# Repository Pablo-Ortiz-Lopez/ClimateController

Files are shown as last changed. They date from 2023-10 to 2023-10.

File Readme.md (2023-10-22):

# ClimateController

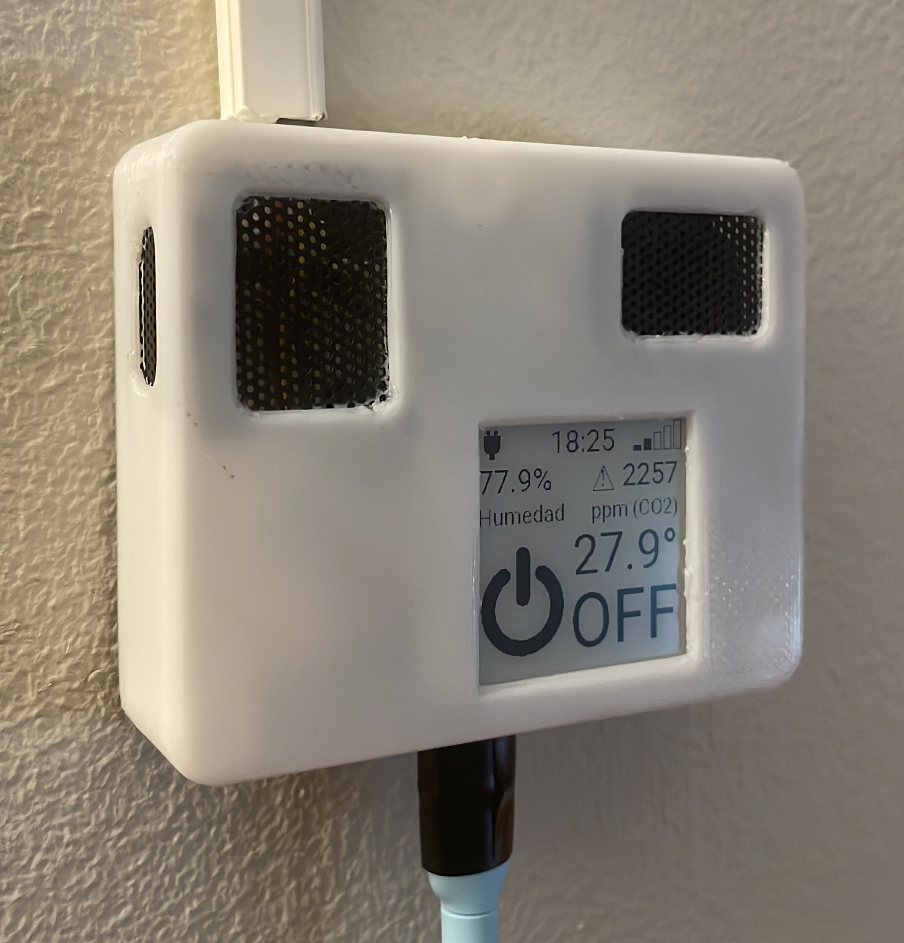
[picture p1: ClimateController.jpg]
My ClimateController


This is my attempt at creating a climate controller for my IOT platform. 

This repository contains everything you need to build and customize your very own ESP8266-based climate controller. 

Whether you want to monitor temperature, humidity, CO2 levels, control a thermostat, manage appliances with a relay, or even handle IR-based air conditioning units, the ClimateController has you covered. 

This README will guide you through the repository's contents and how to get started with your climate controller project. Keep in mind this project was tailor made to cover my needs, so it will most likely need some adaptations for your use case. Feel free to ask me anything you may need about the project.

## Contents

This repository is organized into three main folders, each serving a unique purpose for your climate controller project:

### 1. Electronics

The "electronics" folder contains all the hardware-related materials you'll need:

- **Schematic**: Find the schematic diagram that outlines the electrical connections and components used in the climate controller.

- **PCB Design**: Get the PCB (Printed Circuit Board) design files to manufacture your own climate controller board. You can customize it to suit your needs or use the provided design.

- **KiCad Project**: The KiCad project files are available for further customization and refinement of the PCB design.

### 2. External Case

In the "external_case" folder, you'll find everything related to the physical housing of your climate controller:

- **Fusion360 Project**: Access the Fusion360 project, which contains the 3D model of the external case. You can modify and personalize the design to your liking.

- **Pregenerated Case Designs**: I've included pregenerated presets in .3mf format for 3D printing the external case. Use these presets if you don't have access to Fusion360.

### 3. Firmware

The "firmware" directory contains:

- **Example YAML File**: Use the provided YAML file as a starting point for programming your climate controller with ESPHome. You can adapt and expand upon this file to tailor the device's behavior to your needs.

## Device Features

The ClimateController is highly customizable and can be configured to suit your unique requirements. Here are some of the device's capabilities:

- **Temperature and Humidity Readings**: Monitor environmental temperature and humidity levels.

- **CO2 Readings**: Measure and track carbon dioxide levels in your surroundings.

- **Thermostat Control**: Control a thermostat or other appliances using a relay. This feature enables you to manage heating or cooling systems and other devices with ease.

- **IR-Based Air Conditioner Control**: Remotely manage IR-based air conditioning units for optimal climate control.

- **Display Options**: Choose between an OLED or E-INK display, offering flexibility for your preferred user interface.

## Getting Started

To begin your ClimateController project, follow these steps:

1. Clone this repository to your local machine using Git:
   ```
   git clone git@github.com:Pablo-Ortiz-Lopez/ClimateController.git
   ```

2. Explore the relevant folders to access the hardware and firmware resources.

3. Customize the PCB design, 3D case model, and firmware according to your project requirements.

4. Manufacture the PCB and 3D print the external case.

5. Load and customize the provided yml file into ESPHome, and then load it into the device. If you don't already have an ESPHome environment, I recommend looking into my [HomePanel](https://github.com/Pablo-Ortiz-Lopez/HomePanel) project.

6. Assemble the components and enjoy your personalized climate controller.

## Contributing

If you have improvements, bug fixes, or new features to contribute to the ClimateController project, feel free to create a pull request. I will welcome your contributions and ideas to make this project even better.

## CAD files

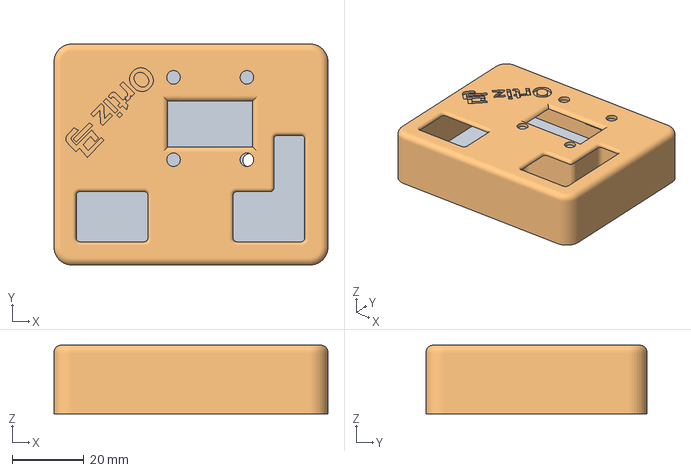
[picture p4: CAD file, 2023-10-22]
external_case/ClimateController External Case OLED display.3mf
76.5 x 61.8 x 19.2 mm
Back Cover
Front Cover

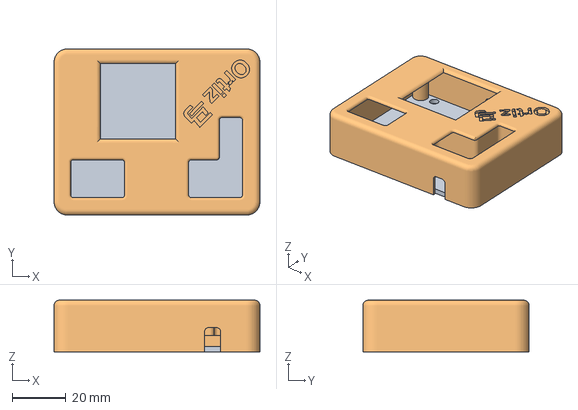
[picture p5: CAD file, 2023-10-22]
external_case/ClimateController External Case EINK display + IR.3mf
76.5 x 61.8 x 19.2 mm
Back Cover
Front Cover

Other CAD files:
external_case/ClimateController External Case EINK display.3mf
external_case/ClimateController External Case OLED display + IR.3mf
external_case/ClimateController External Case.f3d

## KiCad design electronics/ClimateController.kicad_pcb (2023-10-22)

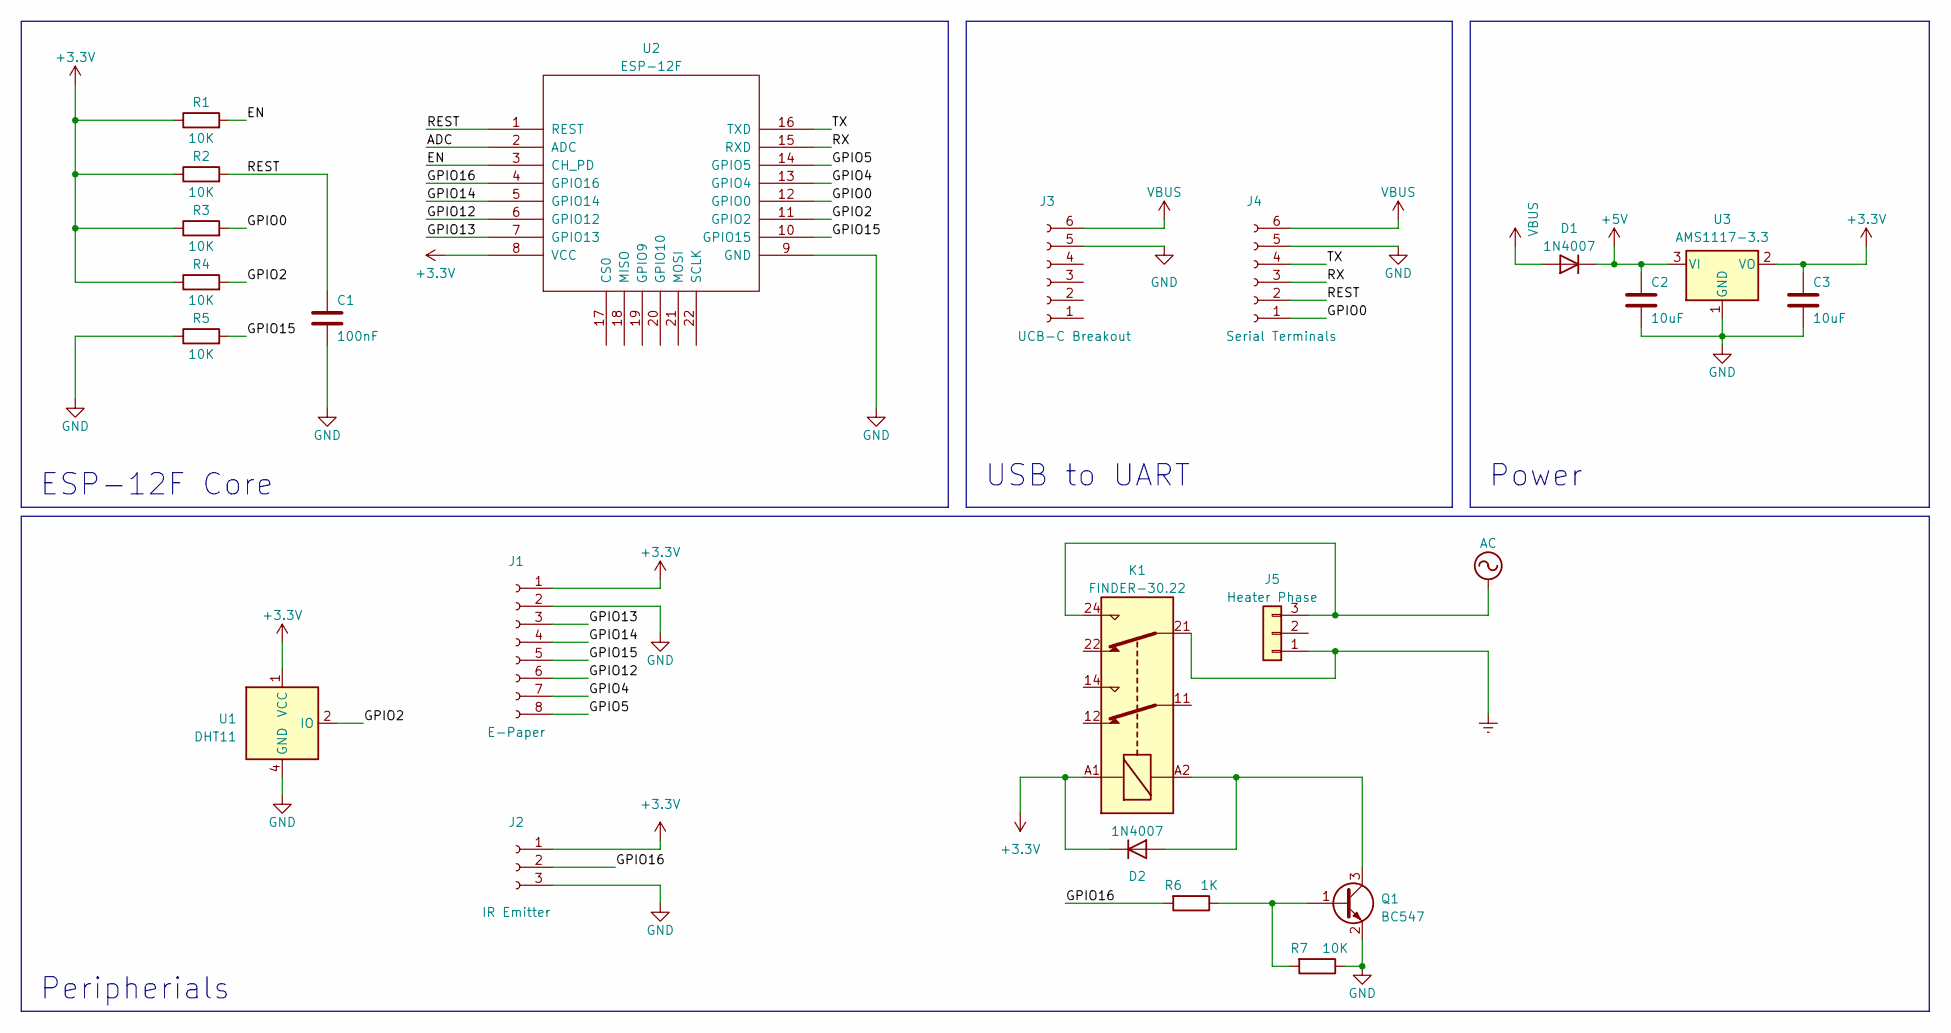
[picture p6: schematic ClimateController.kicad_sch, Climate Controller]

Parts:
C1: 100nF; C_1210_3225Metric_Pad1.33x2.70mm_HandSolder
C2, C3: 10uF; C_1210_3225Metric_Pad1.33x2.70mm_HandSolder
D1, D2: 1N4007; D_SMA_Handsoldering
J1: E-Paper; JST_PH_B8B-PH-K_1x08_P2.00mm_Vertical
J2: IR Emitter; JST_PH_B3B-PH-K_1x03_P2.00mm_Vertical
J3: UCB-C Breakout; USB-C Breakout
J4: Serial Terminals; JST_PH_B6B-PH-K_1x06_P2.00mm_Vertical
J5: Heater Phase; TerminalBlock_bornier-3_P5.08mm
K1: FINDER-30.22; Relay_DPDT_Finder_30.22
Q1: BC547; SOT-23
R1, R2, R3, R4, R5, R7: 10K; R_1206_3216Metric_Pad1.30x1.75mm_HandSolder
R6: 1K; R_1206_3216Metric_Pad1.30x1.75mm_HandSolder
U1: DHT11; Aosong_DHT11_5.5x12.0_P2.54mm
U2: ESP-12F; ESP-12E_SMD
U3: AMS1117-3.3; SOT-223-3_TabPin2

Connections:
+3.3V: C3.1, D2.1 (K), J1.1, J2.1, K1.A1, R1.1, R2.1, R3.1, R4.1, U1.1 (VCC), U2.8 (VCC), U3.2 (VO)
+5V: C2.1, D1.1 (K), U3.3 (VI)
/ADC: U2.2 (ADC)
/EN: R1.2, U2.3 (CH_PD)
/GPIO0: J4.1, R3.2, U2.12 (GPIO0)
/GPIO2: R4.2, U1.2 (IO), U2.11 (GPIO2)
/GPIO4: J1.7, U2.13 (GPIO4)
/GPIO5: J1.8, U2.14 (GPIO5)
/GPIO12: J1.6, U2.6 (GPIO12)
/GPIO13: J1.3, U2.7 (GPIO13)
/GPIO14: J1.4, U2.5 (GPIO14)
/GPIO15: J1.5, R5.2, U2.10 (GPIO15)
/GPIO16: J2.2, R6.2, U2.4 (GPIO16)
/REST: C1.1, J4.2, R2.2, U2.1 (REST)
/RX: J4.3, U2.15 (RXD)
/TX: J4.4, U2.16 (TXD)
AC: J5.3, K1.24
Earth: J5.1, K1.21
GND: C1.2, C2.2, C3.2, J1.2, J2.3, J3.5, J4.5, Q1.2 (E), R5.1, R7.1, U1.4 (GND), U2.9 (GND), U3.1 (GND)
unnamed: D2.2 (A), K1.A2, Q1.3 (C)
unnamed: Q1.1 (B), R6.1, R7.2
VBUS: D1.2 (A), J3.6, J4.6

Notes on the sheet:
Peripherials
USB to UART
Power
ESP-12F Core

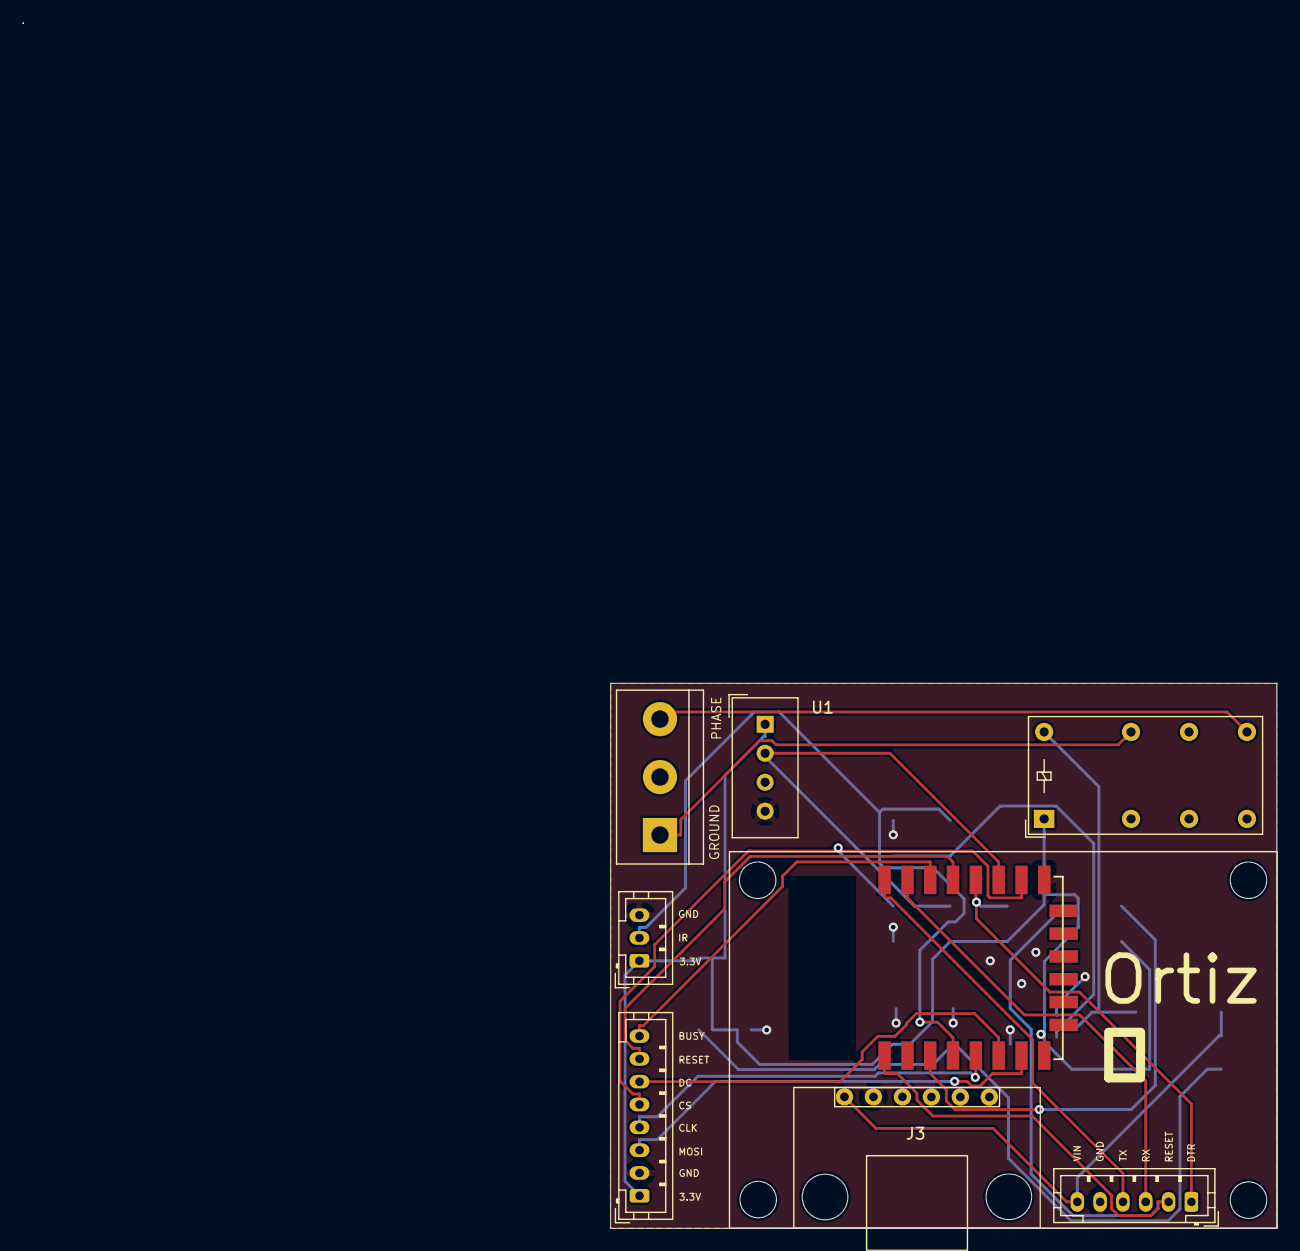
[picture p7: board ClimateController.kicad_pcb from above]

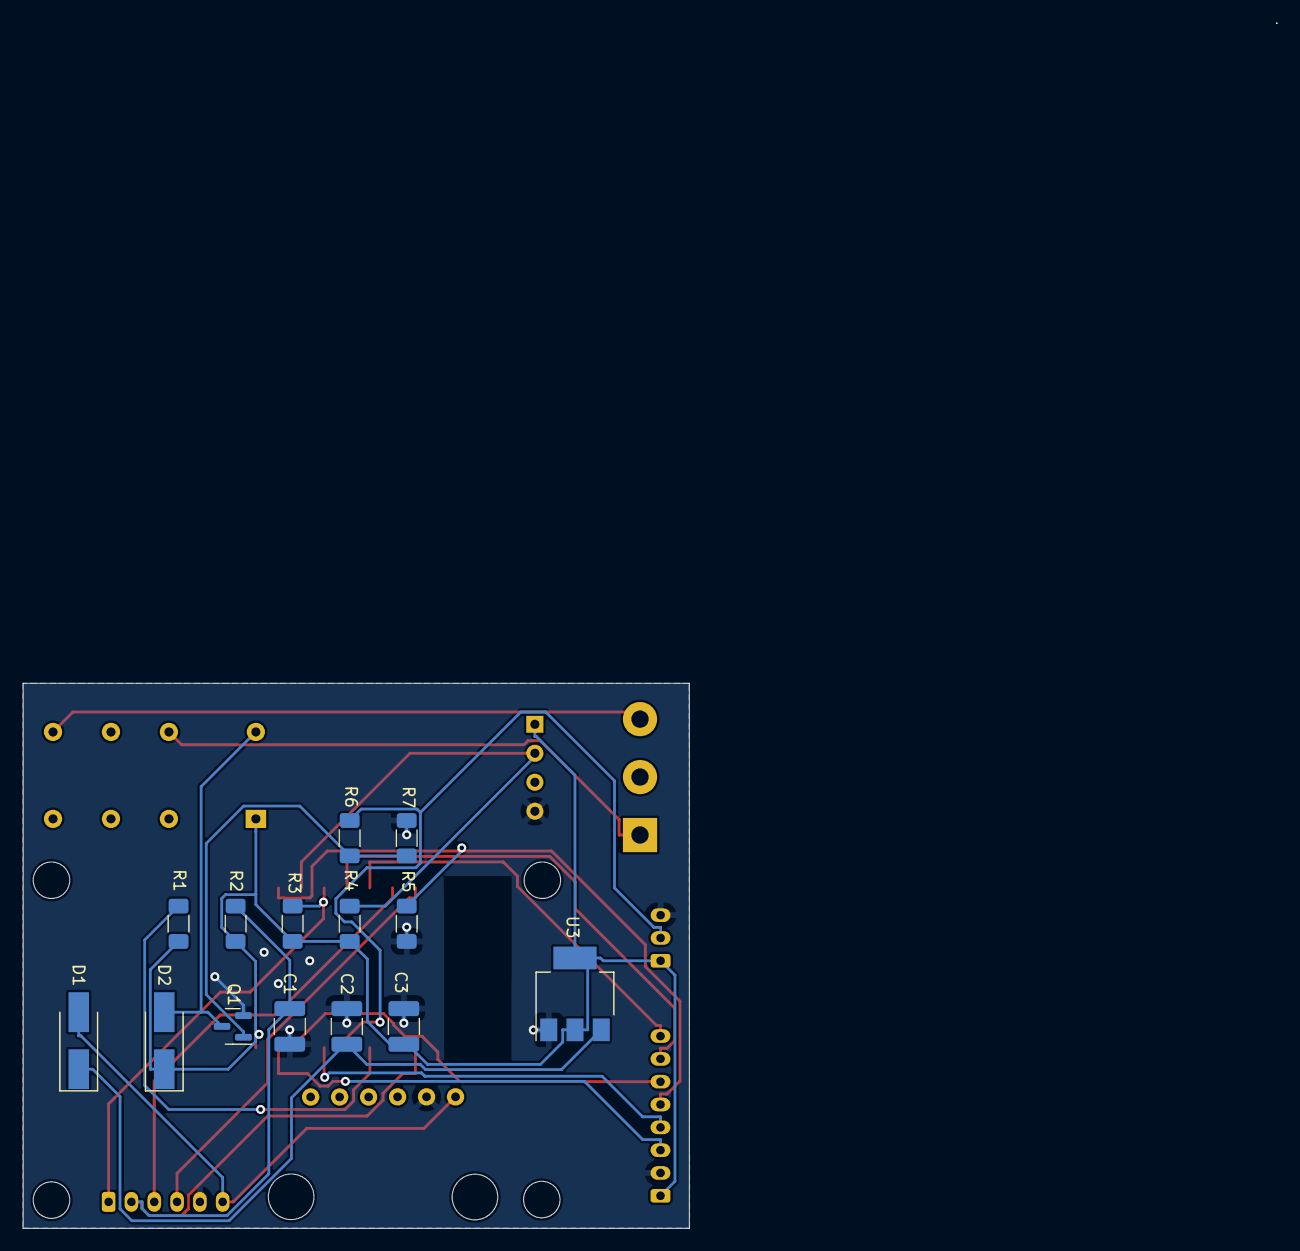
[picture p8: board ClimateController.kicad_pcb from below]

Board: 2 copper layers, 58.4 x 47.8 mm, 23 parts (14 on the bottom side), 21 nets.

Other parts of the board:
E-Ink Screen: 1.54in

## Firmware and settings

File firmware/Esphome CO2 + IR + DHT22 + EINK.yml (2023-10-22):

esphome:
  name: "room-climate"
  friendly_name: "Climatizador del Dormitorio"

esp8266:
  board: esp01_1m

logger:
  level: info
  baud_rate: 0

api:

ota:

wifi:
  ssid: !secret wifi_ssid
  password: !secret wifi_password

  ap:
    ssid: "OrtizMa Room Climate"
    password: !secret mqtt_password

captive_portal:

mqtt:
  broker: !secret mqtt_broker
  username: "pablo"
  password: !secret mqtt_password
  id: mqtt_client

remote_transmitter:
  pin: GPIO16
  carrier_duty_percent: 50%

climate:
  - platform: mitsubishi
    name: "AC"
    id: ac
    on_control:
      - delay: 1s
      - component.update: eink
    sensor: temperature

uart:
  rx_pin: GPIO3
  tx_pin: GPIO1
  baud_rate: 9600
  
sensor:
  - platform: senseair
    co2:
      name: "co2"
      id: co2
    update_interval: 60s
  - platform: dht
    pin: GPIO2
    temperature:
      name: "Temperature"
      id: temperature
      filters:
        - calibrate_linear:
          - 30.1 -> 24.4
          - 30.6 -> 24.8
          - 31.1 -> 25.8
          - 31.4 -> 26
          - 32 -> 26.6
    humidity:
      name: "Humidity"
      id: humidity
      filters:
        offset: 10
          
    update_interval: 15s
    
  - platform: wifi_signal
    name: "WiFi Signal"
    id: wifi_db
    update_interval: 5s

image:
  - file: "images/x.png"
    id: x_image
    resize: 25x25
    type: TRANSPARENT_IMAGE
  - file: "images/fire.png"
    id: fire_image
    resize: 70x70
    type: TRANSPARENT_IMAGE
  - file: "images/snowflake.png"
    id: snowflake_image
    resize: 55x55
    type: TRANSPARENT_IMAGE
  - file: "images/power.png"
    id: power_image
    resize: 90x90
    type: TRANSPARENT_IMAGE
  - file: "images/plug.png"
    id: plug_image
    resize: 25x25
    type: TRANSPARENT_IMAGE
    
font:
  - file: "gfonts://Roboto"
    id: roboto18
    size: 18
  - file: "gfonts://Roboto"
    id: roboto
    size: 25
  - file: "gfonts://Roboto"
    id: roboto_mid
    size: 45
  - file: "gfonts://Roboto"
    id: roboto_big
    size: 60

time:
  - id: reloj
    platform: sntp
    timezone: Europe/Madrid

spi:
  clk_pin: GPIO14
  mosi_pin: GPIO13

display:
  - platform: waveshare_epaper
    id: eink
    cs_pin: GPIO15
    dc_pin: GPIO12
    reset_pin: GPIO4
    busy_pin: GPIO5
    model: 1.54inv2
    rotation: 270
    full_update_every: 1
    update_interval: 60s
    reset_duration: 200ms
    lambda: |-
      it.image(5, 8, id(plug_image));
      
      auto time = id(reloj).now();
      
      if(time.is_valid()){
        it.printf(70,5,id(roboto), TextAlign::TOP_LEFT, "%02d:%02d", time.hour, time.minute);
      }

      if(id(wifi_db).has_state()){ // WIFI OK
        if (!id(mqtt_client)->is_connected()) { // MQTT KO
          it.printf(175, 5, id(roboto), TextAlign::TOP_LEFT , "!");
        }else{ // WIFI & MQTT OK
          it.filled_rectangle(150, 25, 8, 5); // 1 Bar

          if(id(wifi_db).has_state() && id(wifi_db).state > -90){ // 2 Bars
            it.filled_rectangle(160, 20, 8, 10);
          }else{
            it.rectangle(160, 20, 8, 10);
          }

          if(id(wifi_db).has_state() && id(wifi_db).state > -80){ // 3 Bars
            it.filled_rectangle(170, 15, 8, 15);
          }else{
            it.rectangle(170, 15, 8, 15);
          }

          if(id(wifi_db).has_state() && id(wifi_db).state > -70){ // 4 Bars
            it.filled_rectangle(180, 10, 8, 20);
          }else{
            it.rectangle(180, 10, 8, 20);
          }

          if(id(wifi_db).has_state() && id(wifi_db).state > -60){ // 5 Bars
            it.filled_rectangle(190, 5, 8, 25);
          }else{
            it.rectangle(190, 5, 8, 25);
          }
        }
      }else{ // WIFI KO
        it.image(175, 5, id(x_image));
      }
      
      if (id(humidity).has_state()) { // Humidity
        it.printf(5, 65, id(roboto), TextAlign::BOTTOM_LEFT , "%.1f%%", id(humidity).state);
      }else{
        it.printf(5, 65, id(roboto), TextAlign::BOTTOM_LEFT , "--.-%%");
      }
      it.printf(5, 88, id(roboto18), TextAlign::BOTTOM_LEFT , "Humedad");

      if (id(co2).has_state()) { //CO2
        if(id(co2).state > 1500){
          it.printf(118, 62, id(roboto18), TextAlign::BOTTOM_LEFT , "!");
          it.line(110, 60, 120, 40);
          it.line(120, 40, 130, 60);
          it.line(130, 60, 110, 60);
        }
        it.printf(195, 65, id(roboto), TextAlign::BOTTOM_RIGHT , "%.0f", id(co2).state);
      }else{
        it.printf(195, 65, id(roboto), TextAlign::BOTTOM_RIGHT , "- - -");
      }
      it.printf(195, 88, id(roboto18), TextAlign::BOTTOM_RIGHT , "ppm (CO2)");
      
      if (id(temperature).has_state()) { // Temperature
        it.printf(195, 138, id(roboto_mid), TextAlign::BOTTOM_RIGHT , "%.1f°", id(temperature).state);
      }else{
        it.printf(195, 138, id(roboto_mid), TextAlign::BOTTOM_RIGHT , "--.-°");
      }
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

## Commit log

2023-10-22 Ignore files
    [ac-control-B_Cu.gbr, ac-control-B_Mask.gbr, ac-control-B_Paste.gbr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]
2023-10-22 Add case & firmware examples & readme
    [ClimateController External Case EINK display + IR.3mf, ClimateController External Case EINK display.3mf, ClimateController External Case OLED display + IR.3mf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]
